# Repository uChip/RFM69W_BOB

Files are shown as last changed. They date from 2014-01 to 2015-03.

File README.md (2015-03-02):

# Breakout PCB for RFM69W radio transceiver 

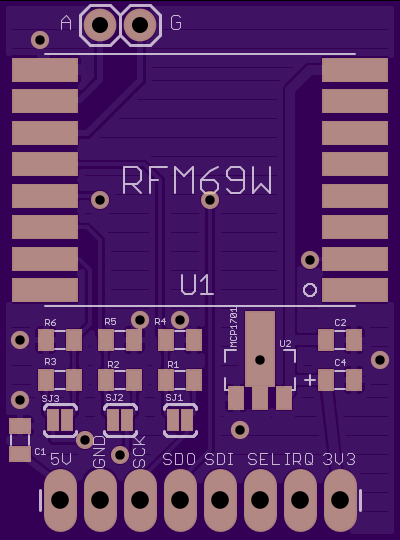
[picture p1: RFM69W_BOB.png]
RFM69W Breakout Board
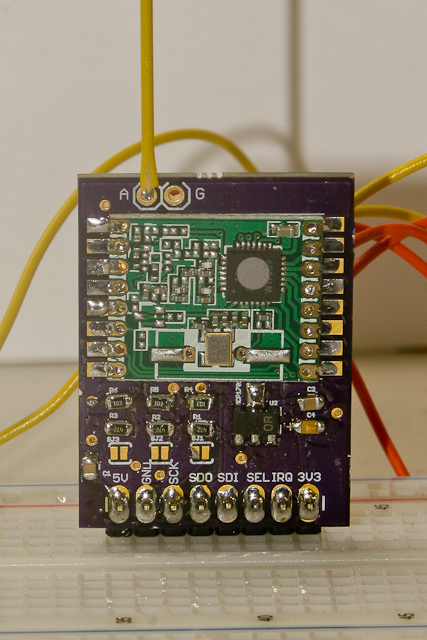
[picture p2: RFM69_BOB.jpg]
RFM69W Breakout Board in action
___

Eagle CAD PCB designs for radio transceiver breakout board. 
Converts the RFM69W radio transceiver from SMT to 0.1" breadboard format.  This board uses the same pinout as the [JeeLabs RFM12B breakout board] (http://www.digitalsmarties.net/products/rfm12b-board) for compatibility.  Note you cannot solder the RFM12B or the RFM69CW modules to this board.  Use an RFM69W or RFM69HW module instead.

See the following link for Arduino drivers for the RFM69W  
  * https://github.com/LowPowerLab/RFM69

A modified version of the RFM69 drivers that allows interchange between RFM69s and RFM12Bs is available in my github (forked from https://github.com/aanon4/RFM69).

Hookup of the breakout board to 5V Arduino SPI connection.  All board components populated.  Solder-jumpers left open.  

	Arduino			RFM69W BOB  
	  5V	-->		  5V  
	  GND	<-->	  GND  
	  D11	-->		  SDI  
	  D12	<--		  SDO  
	  D13	-->		  SCK  
	  D10	-->		  SEL  
	  D2	<--		  IRQ  
	  		<--		  3V3  
 
Hookup of the breakout board to 3.3V Arduino SPI connection.  On PCB populate only radio module, antenna, C2 and C4.  Short the pads on the solder-jumpers.  

	Arduino			RFM69W BOB  
	  NC	 		  5V  
	  GND	<-->	  GND  
	  D11	-->		  SDI  
	  D12	<--		  SDO  
	  D13	-->		  SCK  
	  D10	-->		  SEL  
	  D2	<--		  IRQ  
 	  3.3V	-->		  3V3  

## Order PCBs  

You can order this PCB directly from OSH Park.  Click on the following link.  
  * Radio Breakout - http://oshpark.com/shared_projects/bJRprI06  

See Bill of Materials file in repo for parts list.  

## Status  
  * PCB layout has been tested to be functional.   

## File Formats  

Design files are in "CadSoft EAGLE PCB Design Software" .brd and .sch formats.  
A free version of the software can be downloaded from www.cadsoftusa.com.  

## Distribution License  

You may use this PCB design however you like but no liability is accepted.

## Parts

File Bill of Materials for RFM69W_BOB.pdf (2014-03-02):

## Bill of Materials for RFM69W_BOB

## By Component ID

Part | Value | Device | Package | Description | Comment
C1 | 0.1uF | CAP0805 | 0805 | Capacitor
C2 | 0.1uF | CAP0805 | 0805 | Capacitor
C4 | 10uF | CAP_POL0805 | 0805-POL | Capacitor, Tantalum | Could likely substitute electrolytic with no ill effects.
JP1 | 8 pins | 1X08_RIGHT_ANGLE | | Header 8
R1 | 4k7 | RESISTOR0805-RES | 0805 | Resistor
R2 | 4k7 | RESISTOR0805-RES | 0805 | Resistor
R3 | 4k7 | RESISTOR0805-RES | 0805 | Resistor
R4 | 10k | RESISTOR0805-RES | 0805 | Resistor
R5 | 10k | RESISTOR0805-RES | 0805 | Resistor
R6 | 10k | RESISTOR0805-RES | 0805 | Resistor
U1 | RFM69W | RFM69W | Module | Radio Transceiver Module | Untested, but you can likely substitute RFM69HW for more power.
U2 | MCP1701 | MCP1701 | SOT-89 | Voltage Regulator, LDO | 3.3volt

## Order List

Qty | Parts | Value | Mfg Part # | Description / Vendor
1 | JP1 | 8-pins | | Break Away Male Headers - Right Angle https://www.sparkfun.com/products/553[/
1 | PCB | | RFM69W Breakout Board | http://oshpark.com/shared_projects/bJRprI06
2 | C1, C2 | 0.1uF | C2012X7R2A104K125AA | CAP CER 0.1UF 100V 10% X7R 0805 Digi-Key #445-1418-1-ND
3 | R4, R5, R6 | 10k | ERJ-6GEYJ103V | RES 10K OHM 1/8W 5% 0805 SMD Digi-Key #P10KACT-ND
1 | C4 | 10uF | F951A106MRAAQ2 | CAP TANT 10UF 10V 20% 0805 Digi-Key #478-8418-1-ND
3 | R1, R2, R3 | 4k7 | ERJ-6GEYJ472V | RES 4.7K OHM 1/8W 5% 0805 SMD Digi-Key #P4.7KACT-ND
1 | U2 | MCP1701 | MCP1701AT-3302I/MB | IC REG LDO 3.3V 0.15A SOT89-3 Digi-Key #MCP1701AT-3302I/MBCT-ND
1 | U1 | RFM69W | RFM69W-S2 | http://lowpowerlab.com/shop/RFM69W

Note that all parts are "or equivalent". These are the parts I tested with, but you can probably substitute parts with no impact on performance. For instance, any 0805 package 10k resistor would be fine.

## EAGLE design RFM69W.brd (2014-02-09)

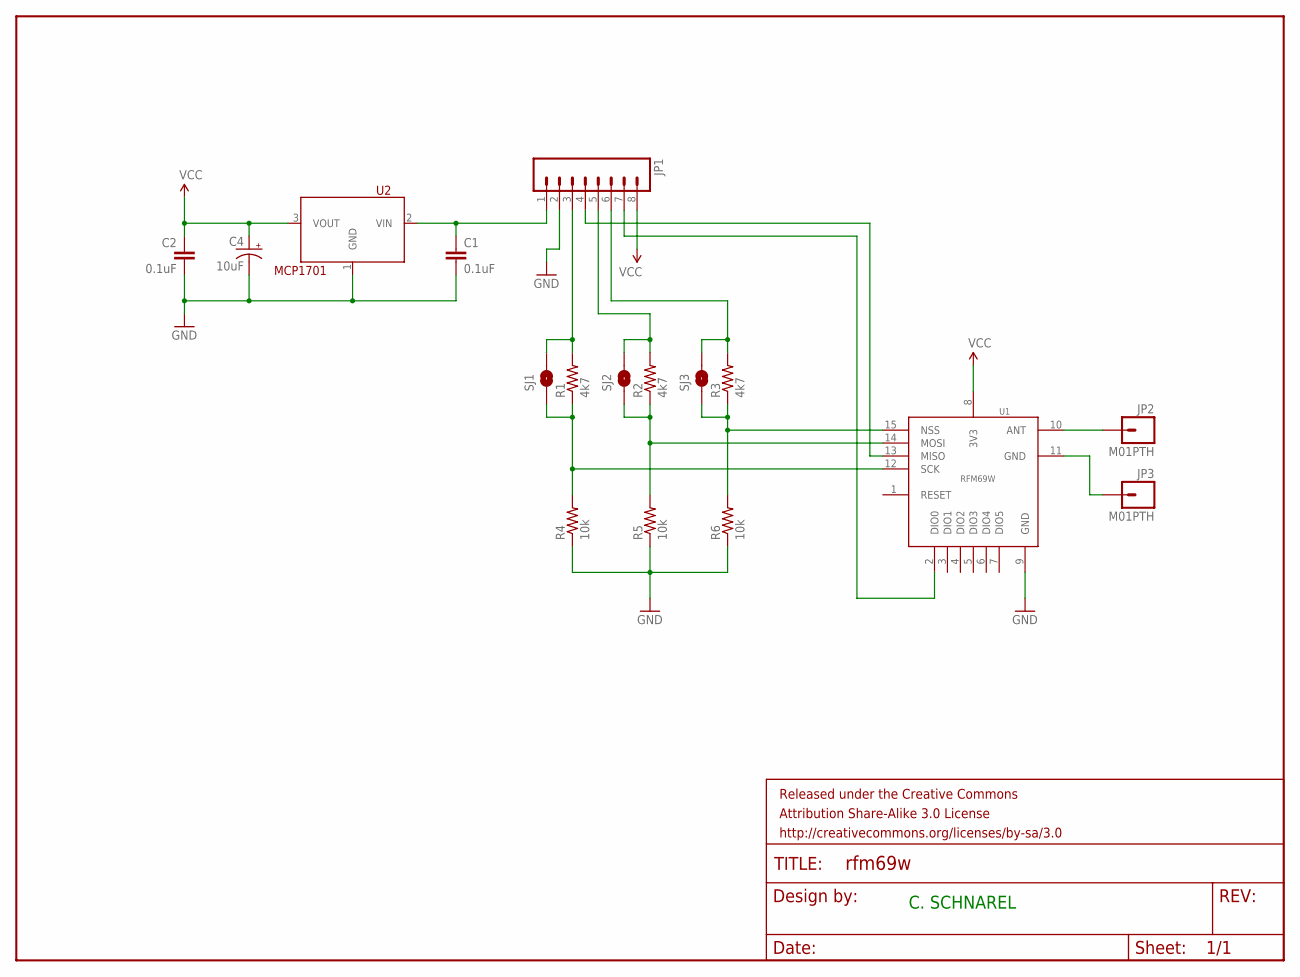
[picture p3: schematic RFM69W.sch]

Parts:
C1, C2: 0.1uF; 0805
C4: 10uF; 0805-POL
FRAME1: FRAME-LETTER; CREATIVE_COMMONS
JP1: M08LONGPADS; 1X08_LONGPADS
JP2, JP3: M01PTH; 1X01
R1, R2, R3: 4k7; 0805
R4, R5, R6: 10k; 0805
SJ1, SJ2, SJ3: SOLDERJUMPERNO; SJ_2S-NO
U1: RFM69W
U2: MCP1701; SOT-89

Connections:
GND: C1.2, C2.2, C4.2 (-), JP1.2, R4.1, R5.1, R6.1, U1.9 (GND), U2.1 (GND)
unnamed: R3.1, R6.2, SJ3.1, U1.15 (NSS)
unnamed: C1.1, JP1.1, U2.2 (VIN)
unnamed: JP1.4, U1.13 (MISO)
unnamed: JP1.7, U1.2 (DIO0)
unnamed: R2.1, R5.2, SJ2.1, U1.14 (MOSI)
unnamed: JP1.3, R1.2, SJ1.2
unnamed: JP1.5, R2.2, SJ2.2
unnamed: JP1.6, R3.2, SJ3.2
unnamed: R1.1, R4.2, SJ1.1, U1.12 (SCK)
unnamed: JP2.1, U1.10 (ANT)
unnamed: JP3.1, U1.11 (GND)
VCC: C2.1, C4.1 (+), JP1.8, U1.8 (3V3), U2.3 (VOUT)

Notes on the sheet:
C. SCHNAREL

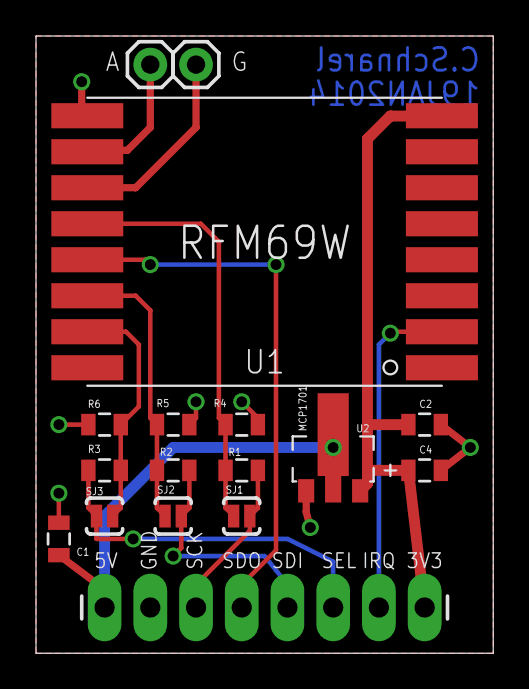
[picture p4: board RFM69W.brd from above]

Board: 2 copper layers, 25.4 x 34.3 mm, 18 parts (0 on the bottom side), 13 nets.

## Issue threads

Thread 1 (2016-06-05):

Break-out board issues

REHolt, 2016-06-05:
I am attempting to use your RFM69HW Breakout board, but not having much luck. I purchased 3 of the boards from OSH Park and assembled them for use with the Arduino Uno 3.3v supply. Two of them are assembled as "Half Shields" with discrete wires of the 3.3v and IRQ0. I also installed an LED and a push button on my shield to run the TxRxBlinky code available on the LOWPOWERLAB github.

Do you know if the board works in this configuration? one of the indications I get is that the RFM69HW may be pulling too much current for the 3.3v supply. I will be ordering some 5v to 3.3v converters to verify this, but was hoping you might know the answer. Also, what other resources might be available to tell if the board is even working? I have tried several Tx/Rx programs but can truly tell what is going on.

Any suggestions or insight would be appreciated.
Robert

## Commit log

2014-01-19 Initials Commit
    This is a breakout board (Eagle PCB design) for the HopeRF RFM69W radio
    transceiver
    [RFM69W.brd, RFM69W.sch]
2014-01-19 Adding .png of board
2014-02-09 Updated README to confirm tested
    Also filled in value on bypass cap.
    [RFM69W.brd, RFM69W.sch]
2014-02-13 Added BOM file
2014-02-13 Updated README to reference BOM file
2014-02-27 Updating docs with new picture of working board.
2014-03-02 Updating picture & README
    Image was wrong board. Changing to the right one.
2014-03-02 Corrected error in BOM

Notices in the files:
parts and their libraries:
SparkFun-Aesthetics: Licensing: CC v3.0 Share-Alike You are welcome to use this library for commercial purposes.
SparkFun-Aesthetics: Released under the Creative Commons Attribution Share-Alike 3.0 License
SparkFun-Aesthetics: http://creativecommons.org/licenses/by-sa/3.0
